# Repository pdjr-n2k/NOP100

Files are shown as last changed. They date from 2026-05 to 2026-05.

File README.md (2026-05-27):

# NOP100

The **NOP100** project implements a generic
[NMEA 2000](https://en.wikipedia.org/wiki/NMEA_2000)
module with on-board support for
[MikroBUS](https://www.mikroe.com/mikrobus)
and
[OneWire]()
devices.

Twin MikroBUS sockets allow specialisation of function by the addition of
[Click](https://www.mikroe.com/click)
expansion cards and appropriate software extensions.

[**NOP100** hardware](./hardware/README.md)
is based on the Teensy 4.0 micro-controller supported by a CAN
transceiver, parasitic power supply and a user configuration
interface.

[**NOP100** firmware](./firmware/README.md)
manages NMEA 2000 connectivity, user interaction and module
configuration and is easily extended by the addition of firmware
dedicated to interfacing any installed MikroBus and OneWire devices.

## Project organisation

```
NOP100/
  + firmware/            # NOP100 firmware...
    + modules/           # Folders for module specialisations
      + NOP100-SIM/        # Specialisation defining an NMEA switch input module
        + defines.h
        + definitions.h
        + includes.h
        + loop.h
        + setup.h
      + another module specialisation/
      + .../
    + NOP100.cpp         # NOP100 main application 
    + README.md
    + defines.h          # Symbolic link to a module specialisation
    + definitions.h      #   "       "
    + includes.h         #   "       "
    + loop.h             #   "       "
    + setup.h            #   "       "
  + hardware/            # NOP100 hardware...
    + gerber/            # Gerber files for PCB fabrication
    + kicad/             # Kicad design for the NOP100 motherboard
    + README.md
```

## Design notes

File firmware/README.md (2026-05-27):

# NOP100/firmware

```NOP100.cpp``` implements a runnable, extensible, firmware for
[NOP100-based hardware](../hardware/README.md).

The files defines.h, definitions.h, includes.h, loop.h and setup.h
allow specialisation of NOP100 to a particular application by
extending and overriding some core functionality.

If specialisation is absent, the firmware creates an NMEA 2000
device with Class Code 10 (System Tools) and Function Code 130
(Diagnostic).
The created device is essentially passive, but will respond to
PGN 126208 Group Function Handler commands to update its default
instance address.

Supplying functional content in the specialisation files allows the
construction of a useful NMEA 2000 application.
The recommended way of doing this is to create a folder under the
```modules/``` directory for a planned application and to populate this
with specialisation files that become the target of symbolic links in
the NOP100 folder.

By way of illustration, the ```modules/NOP100-SIM``` folders contains
code which specialises the NOP100 firmware so that it acts as an NMEA
2000 switch input module.
The extended firware supports one or two
[MikroE 5981]()
modules as the external switch input interface.

The modules/CLICK5981 folder, for example, 
Most useful applications will exploit interfaces implemented by
MikroBus modules which plug into the NOP100 motherboard and it is
[SIM108 - NMEA 2000 switch input module](https://www.github.com/preeve9534/SIM108/)
project is based on NOP100 and gives a working example of a real-world
application.

## Module configuration

Modules based on NOP100 are intended to support structured
configuration updates via PGN126208 Command Group Function or by use
of the hardware DIL switch which allows byte-level updates to binary
configuration data. This restricts the configuration data cache to a
size of 256 bytes with 254 bytes available to the application.

The Teensy microcontroller has a about 1KB of EEPROM available and if
you want to access more than 256 bytes of this storage then you will
need to override NOP100's simple configuration model with a more
elaborate one of your own.

If you do this, make sure that your application configuration data
leaves address locations 0 and 1 for use by NOP100.

| Address | Saved value |
| ---:    | :---        |
| 0       | CAN source address. Not available for application use. |
| 1       | Module instance number. Not available for application use. |
| 2...    | Available for application use. |

Entry of configuration data into NOP100 requires a value to be set on
the PCB's DIL switch and then confirmed by press and release of the PRG
button.
A short press of PRG signifies the entry of a data value; a long press
of PRG signifies entry of an address and, in this latter case, the
expectation is that address entry will promptly be followed by the
entry of a data value which should be stored at the pre-set address.

If a value is entered without a preceeding address then the entered
value is stored at address 1 and will become the module's new instance
number.

Storage locations with an address greater than or equal to two are
intended for application configuration data and entry of this data
requires the entry of an address followed by entry of the value to be
stored at this address.

When an address is entered, the transmit LED will flash rapidly
indicating that the system is waiting for entry of a data value.
If a data value is not entered within one minute the data entry protocol
will self-cancel (the transmit LED will stop flashing).

In ```NOP100.cpp``` the configuration process is handled by the
```prgButtonHandler(bool _state_, int _value_)``` function which is
called each time the PRG button is operated.
*state* will be true if the PRG button has been released or false if
the PRG button has been pressed.
In either case, *value* will be set to the current value read from the
DIL switch.

You can override NOP100's built-in behaviour by overriding the button
handler in ```module-declarations.inc```.
For example, the following code disables configuration entirely:
```
#define PRG_BUTTON_HANDLER
void prgButtonHandler(bool state, int value) {
   return;
}
```

## HOW TO

1. Create parent folder for your new application.
   ```
   $> mkdir n2k-projects
   $> cd n2k-projects
   ```
2. Clone a copy of the Arduino firmware build project and this
   project into separate sub-folders.
   ```
   $> git clone https://github.com/preeve9534/firmware-factory
   $> git clone https://github.com/preeve9534/NOP100
   ```
3. Make a directory for your new project and populate it.
   ```
   $> mkdir myapp
   $> cd myapp
   $> cp ../NOP100/NOP100.cpp myapp.cpp
   $> cp ../NOP100/*.inc .
   $> cd ..
   ```
   You can now delete the NOP100 project.
   ```
   rm -rf NOP100
   ```
4. Set up the build environment so that it points to your new
   project.
   ```
   $> cd firmware-factory/sketch
   $> rm src
   $> ln -s ../../myapp src
   $> cd ../..
   ```
   At this juncture you should be able to open the firmware-factory 
   project in your preferred build environment (I use Code) and
   compile a firmware for your application which does nothing. Well,
   not very much.
5. Edit the ```.inc``` files downloaded at (3) to tailor and
   extend the module firmware to the requirements of your
   application.  DO NOT MODIFY myapp.cpp.

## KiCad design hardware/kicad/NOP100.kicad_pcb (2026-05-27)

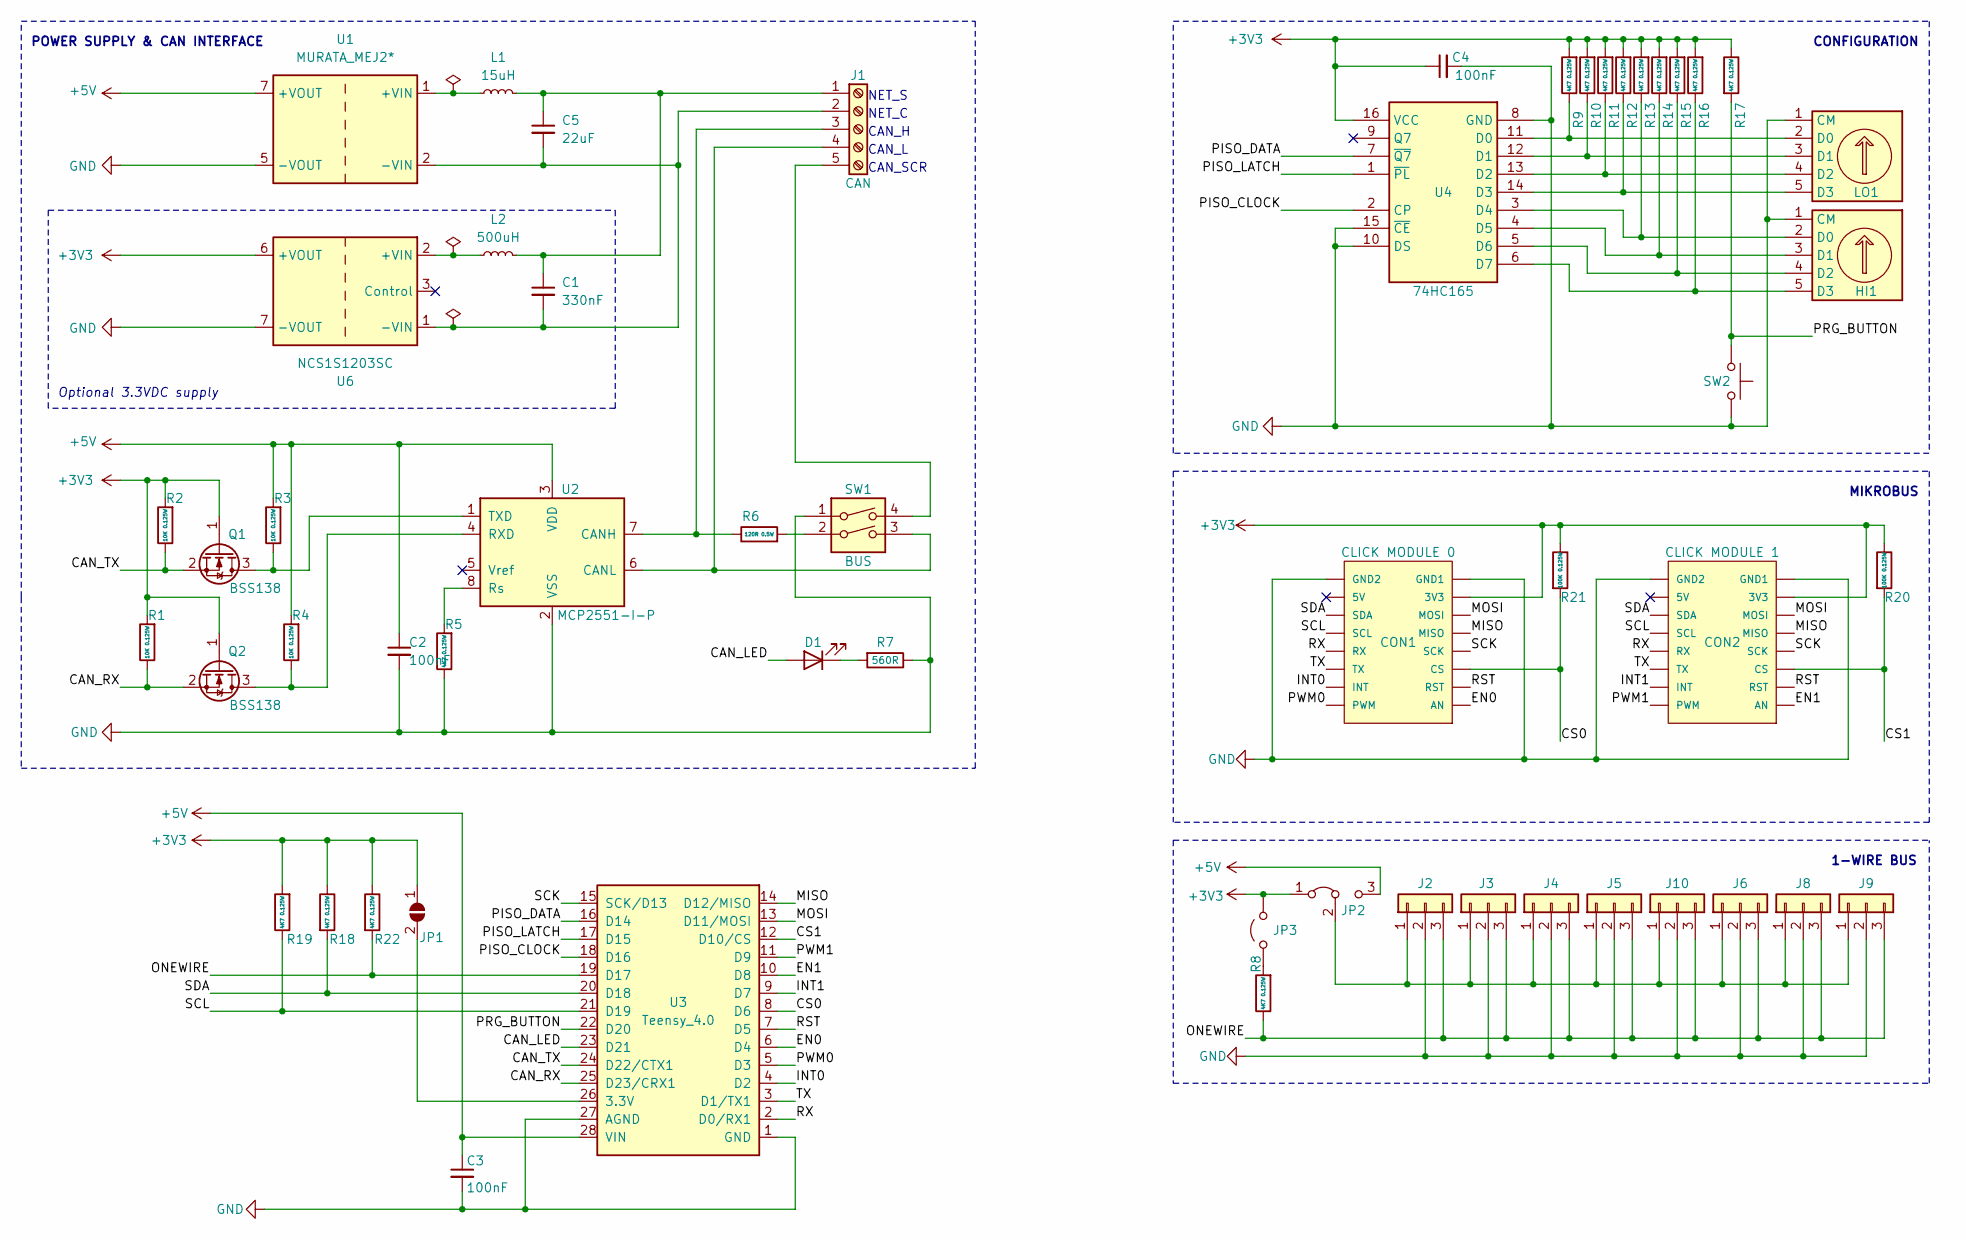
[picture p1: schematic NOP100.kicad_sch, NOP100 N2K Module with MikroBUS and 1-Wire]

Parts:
C1: 330nF; R_1210_3225Metric
C2, C3, C4: 100nF; R_0805_2012Metric
C5: 22uF; R_1210_3225Metric
CON1: CLICK MODULE 0; MIKROBUS_HOST_CONN
CON2: CLICK MODULE 1; MIKROBUS_HOST_CONN
D1: LED; R_0805_2012Metric
HI1: SW_Coded; Nidec_Copal_SH-7010C
J1: CAN; PinHeader_1x05_P2.54mm_Vertical
J2, J3, J4, J5, J6, J8, J9, J10: Conn_01x03; RS_8971054
JP1: SolderJumper_2_Open; SolderJumper-2_P1.3mm_Bridged_Pad1.0x1.5mm
JP2: Jumper_3_Bridged12; PinHeader_1x03_P1.27mm_Vertical
JP3: Jumper_2_Open; PinHeader_1x02_P1.27mm_Vertical
L1: 15uH; L_Bourns_SRN6045TA
L2: 500uH; L_Bourns_SRN6045TA
LO1: SW_Coded; Nidec_Copal_SH-7010C
Q1, Q2: BSS138; SOT-23
R1, R2, R3, R4: 10K 0.125W; R_0805_2012Metric
R5, R8, R9, R10, R11, R12, R13, R14, R15, R16, R17, R18, R19, R22: 4K7 0.125W; R_0805_2012Metric
R6: 120R 0.5W; R_1206_3216Metric
R7: 560R; R_0805_2012Metric
R20, R21: 100K 0.125W; R_0805_2012Metric
SW1: BUS; DIP-4_W7.62mm_LongPads
SW2: SW_Push; SW_SPST_PTS810
U1: MURATA_MEJ2*; Murata-MEJ2*
U2: MCP2551-I-P; SOIC-8_3.9x4.9mm_P1.27mm
U3: Teensy_4.0; DIP-28_W15.24mm_Socket
U4: 74HC165; SOIC-16_3.9x9.9mm_P1.27mm
U6: NCS1S1203SC; Converter_DCDC_Murata_NCS1SxxxxSC_THT

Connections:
+3V3: C4.1, CON1.P7 (3V3), CON2.P7 (3V3), JP1.1 (A), JP2.1 (A), JP3.2 (B), Q1.1 (G), Q2.1 (G), R1.2, R2.2, R9.2, R10.2, R11.2, R12.2, R13.2, R14.2, R15.2, R16.2, R17.1, R18.1, R19.2, R20.1, R21.1, R22.1, U4.16 (VCC), U6.6 (+VOUT)
+5V: C2.1, C3.1, JP2.3 (B), R3.2, R4.2, U1.7 (+VOUT), U2.3 (VDD), U3.28 (VIN)
/CAN_LED: D1.2 (A), U3.23 (D21)
/CAN_RX: Q2.2 (S), R1.1, U3.25 (D23/CRX1)
/CAN_TX: Q1.2 (S), R2.1, U3.24 (D22/CTX1)
/CS0: CON1.P3 (CS), R21.2, U3.8 (D6)
/CS1: CON2.P3 (CS), R20.2, U3.12 (D10/CS)
/EN0: CON1.P1 (AN), U3.6 (D4)
/EN1: CON2.P1 (AN), U3.10 (D8)
/INT0: CON1.P15 (INT), U3.4 (D2)
/INT1: CON2.P15 (INT), U3.9 (D7)
/MISO: CON1.P5 (MISO), CON2.P5 (MISO), U3.14 (D12/MISO)
/MOSI: CON1.P6 (MOSI), CON2.P6 (MOSI), U3.13 (D11/MOSI)
/ONEWIRE: J2.3, J3.3, J4.3, J5.3, J6.3, J8.3, J9.3, J10.3, R8.1, R22.2, U3.19 (D17)
/PISO_CLOCK: U3.18 (D16), U4.2 (CP)
/PISO_DATA: U3.16 (D14), U4.7 (~Q7)
/PISO_LATCH: U3.17 (D15), U4.1 (~PL)
/PRG_BUTTON: R17.2, SW2.1, U3.22 (D20)
/PWM0: CON1.P16 (PWM), U3.5 (D3)
/PWM1: CON2.P16 (PWM), U3.11 (D9)
/RST: CON1.P2 (RST), CON2.P2 (RST), U3.7 (D5)
/RX: CON1.P13 (RX), CON2.P13 (RX), U3.2 (D0/RX1)
/SCK: CON1.P4 (SCK), CON2.P4 (SCK), U3.15 (SCK/D13)
/SCL: CON1.P12 (SCL), CON2.P12 (SCL), R19.1, U3.21 (D19)
/SDA: CON1.P11 (SDA), CON2.P11 (SDA), R18.2, U3.20 (D18)
/TX: CON1.P14 (TX), CON2.P14 (TX), U3.3 (D1/TX1)
GND: C2.2, C3.2, C4.2, CON1.P8 (GND1), CON1.P9 (GND2), CON2.P8 (GND1), CON2.P9 (GND2), HI1.1 (CM), J2.2, J3.2, J4.2, J5.2, J6.2, J8.2, J9.2, J10.2, LO1.1 (CM), R5.1, R7.1, SW1.1, SW2.2, U1.5 (-VOUT), U2.2 (VSS), U3.1 (GND), U3.27 (AGND), U4.8 (GND), U4.10 (DS), U4.15 (~CE), U6.7 (-VOUT)
unnamed: D1.1 (K), R7.2
unnamed: HI1.2 (D0), R13.1, U4.3 (D4)
unnamed: HI1.3 (D1), R14.1, U4.4 (D5)
unnamed: HI1.4 (D2), R15.1, U4.5 (D6)
unnamed: HI1.5 (D3), R16.1, U4.6 (D7)
unnamed: C1.1, C5.1, J1.1, L1.2, L2.2
unnamed: C1.2, C5.2, J1.2, U1.2 (-VIN), U6.1 (-VIN)
unnamed: J1.3, R6.1, U2.7 (CANH)
unnamed: J1.4, SW1.3, U2.6 (CANL)
unnamed: J1.5, SW1.4
unnamed: J2.1, J3.1, J4.1, J5.1, J6.1, J8.1, J9.1, J10.1, JP2.2 (C)
unnamed: JP1.2 (B), U3.26 (3.3V)
unnamed: JP3.1 (A), R8.2
unnamed: LO1.2 (D0), R9.1, U4.11 (D0)
unnamed: LO1.3 (D1), R10.1, U4.12 (D1)
unnamed: LO1.4 (D2), R11.1, U4.13 (D2)
unnamed: LO1.5 (D3), R12.1, U4.14 (D3)
unnamed: Q1.3 (D), R3.1, U2.1 (TXD)
unnamed: Q2.3 (D), R4.1, U2.4 (RXD)
unnamed: R6.2, SW1.2
unnamed: L1.1, U1.1 (+VIN)
unnamed: R5.2, U2.8 (Rs)
unnamed: L2.1, U6.2 (+VIN)

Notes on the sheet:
CONFIGURATION
1-WIRE BUS
MIKROBUS
CAN_H
POWER SUPPLY & CAN INTERFACE
CAN_L
CAN_SCR
NET_C
NET_S
Optional 3.3VDC supply

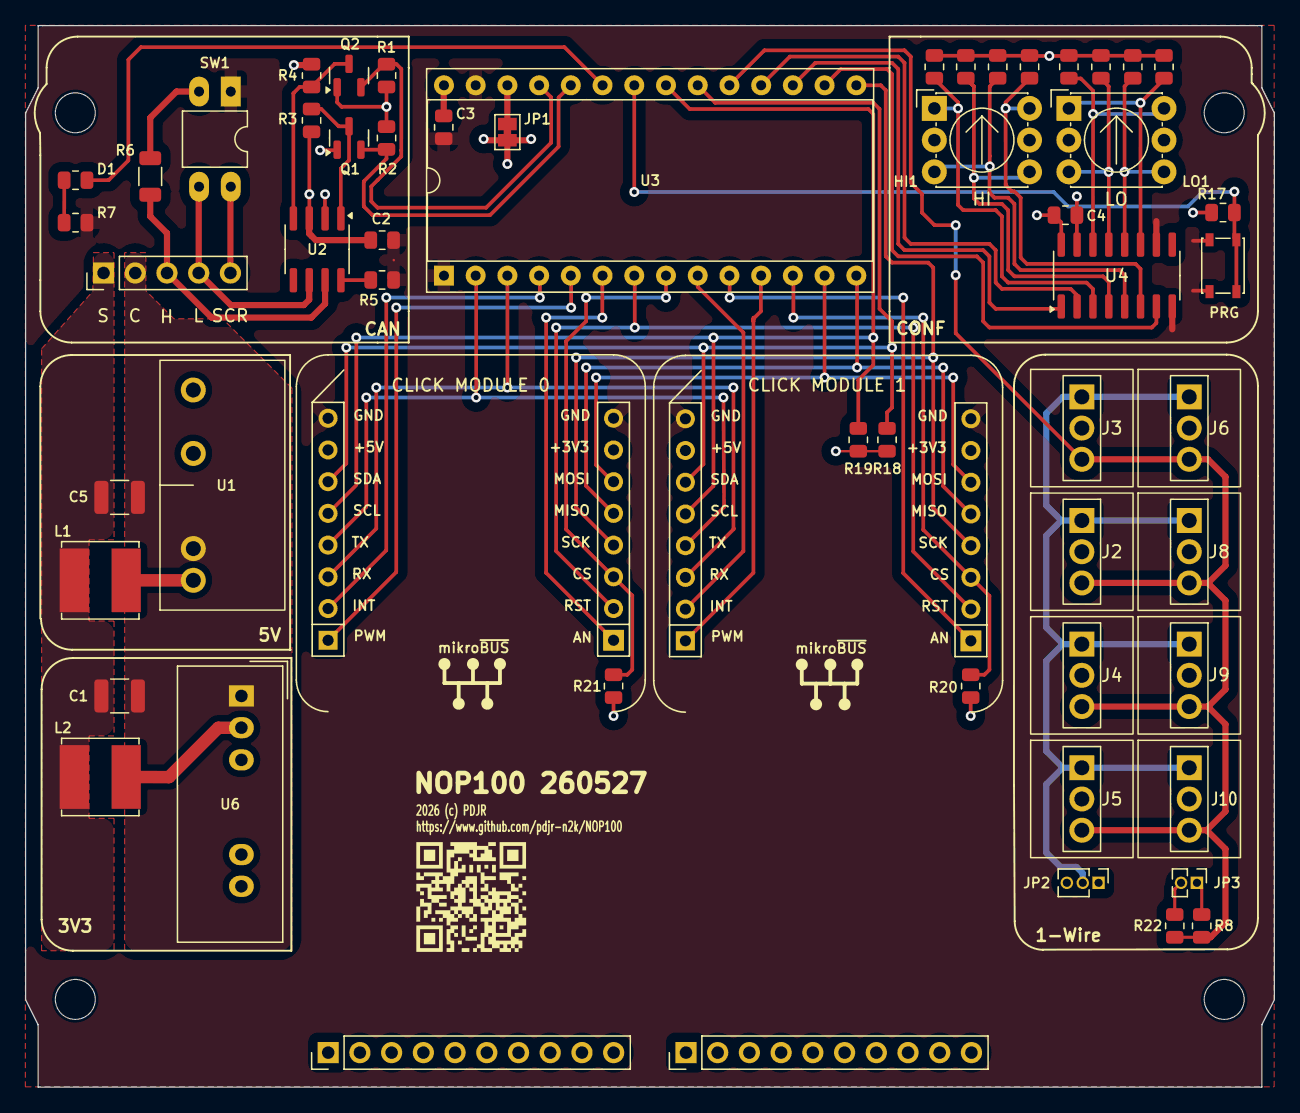
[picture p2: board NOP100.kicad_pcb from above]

Board: 4 copper layers, 100.0 x 85.0 mm, 55 parts (0 on the bottom side), 50 nets.

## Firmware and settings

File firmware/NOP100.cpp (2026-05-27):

/**
 * @file NOP100.cpp
 * @author Paul Reeve (preeve@pdjr.eu)
 * @brief Extensible firmware based on the NMEA2000 library.
 * @version 0.1
 * @date 2023-01-15
 * 
 * @copyright Copyright (c) 2023
 *
 * This firmware is targetted at hardware based on the
 * [NOP100](https://github.com/preeve9534/NOP100)
 * module design.
 * It implements a functional NMEA 2000 device that performs no
 * real-world task, but which can be easily extended or specialised
 * into a variant that can perform most things required of an NMEA 2000
 * module.
 * 
 * Support for NMEA 2000 networking is provided by Timo Lappalainen's
 * [NMEA2000](https://github.com/ttlappalainen/NMEA2000)
 * library.
 * 
 * Support for configuration management and operator interaction
 * is provided by a number of bespoke libraries that relieve derived
 * applications of much of the heavy lifting.
 */

#include <Arduino.h>
#include <EEPROM.h>
#include <NMEA2000.h>
#include <N2kTypes.h>
#include <N2kMessages.h>
#include <NMEA2000_Teensyx.h>
#include <NMEA2000_CAN.h>
#include <Button.h>
#include <IC74HC165.h>
#include <SPI.h>
#include <LedManager.h>
#include <ModuleConfigurator.h>
#include <arraymacros.h>

#include <includes.h>


/**********************************************************************
 * @brief Configure debug output to Teensy serial port.
 */
#define DEBUG_SERIAL
#define DEBUG_SERIAL_PORT_SPEED 9600
#define DEBUG_SERIAL_START_DELAY 4000

/**********************************************************************
 * @brief GPIO pin definitions for Teensy 4.0
 */
#define GPIO_D0 0
#define GPIO_D1 1
#define GPIO_D2 2
#define GPIO_D3 3
#define GPIO_D4 4
#define GPIO_D5 5
#define GPIO_D6 6
#define GPIO_D7 7
#define GPIO_D8 8
#define GPIO_D9 9
#define GPIO_D10 10
#define GPIO_D11 11
#define GPIO_D12 12
#define GPIO_D13 13
#define GPIO_D14 14
#define GPIO_D15 15
#define GPIO_D16 16
#define GPIO_D17 17
#define GPIO_D18 18
#define GPIO_D19 19
#define GPIO_D20 20
#define GPIO_D21 21
#define GPIO_D22 22
#define GPIO_D23 23

#define GPIO_SERIAL_RX GPIO_D0
#define GPIO_SERIAL_TX GPIO_D1
#define GPIO_MIKROBUS_MODULE0_INT GPIO_D2
#define GPIO_MIKROBUS_MODULE0_PWM GPIO_D3
#define GPIO_MIKROBUS_MODULE0_EN GPIO_D4
#define GPIO_MIKROBUS_RST GPIO_D5
#define GPIO_MIKROBUS_MODULE0_CS GPIO_D6
#define GPIO_MIKROBUS_MODULE1_INT GPIO_D7
#define GPIO_MIKROBUS_MODULE1_EN GPIO_D8
#define GPIO_MIKROBUS_MODULE1_PWM GPIO_D9
#define GPIO_MIKROBUS_MODULE1_CS GPIO_D10
#define GPIO_SPI_MOSI GPIO_D11
#define GPIO_SPI_MISO GPIO_D12
#define GPIO_SPI_SCK GPIO_D13
#define GPIO_PISO_DATA GPIO_D14
#define GPIO_PISO_LATCH GPIO_D15
#define GPIO_PISO_CLOCK GPIO_D16
#define GPIO_ONE_WIRE GPIO_D17
#define GPIO_I2C_SDA GPIO_D18
#define GPIO_I2C_SCL GPIO_D19
#define GPIO_BUTTON_PRG GPIO_D20
#define GPIO_LED_CAN GPIO_D21
#define GPIO_CAN_TX GPIO_D22
#define GPIO_CAN_RX GPIO_D23

/**********************************************************************
 * @brief NMEA2000 device information.
 * 
 * Most specialisations of NOP100 will want to override DEVICE_CLASS,
 * DEVICE_FUNCTION and perhaps DEVICE_UNIQUE_NUMBER.
 * 
 * DEVICE_CLASS and DEVICE_FUNCTION are explained in the document
 * "NMEA 2000 Appendix B.6 Class & Function Codes".
 * 
 * DEVICE_INDUSTRY_GROUP we can be confident about (4 says maritime).
 * 
 * DEVICE_MANUFACTURER_CODE is only allocated to subscribed NMEA
 * members so we grub around and use 2046 which is currently not
 * allocated.  
 * 
 * DEVICE_UNIQUE_NUMBER is a bit of mystery.
 */
#define DEVICE_CLASS 10                 // System Tools
#define DEVICE_FUNCTION 130             // Diagnostic
#define DEVICE_INDUSTRY_GROUP 4         // Maritime
#define DEVICE_MANUFACTURER_CODE 2046   // Currently not allocated.
#define DEVICE_UNIQUE_NUMBER 849        // Bump me?

/**********************************************************************
 * @brief NMEA2000 product information.
 * 
 * Specialisations of NOP100 will want to override most of these.
 * 
 * PRODUCT_CERTIFICATION_LEVEL is granted by NMEA when a product is
 * officially certified. We won't be.
 * 
 * PRODUCT_CODE is our own unique numerical identifier for this device.
 * 
 * PRODUCT_FIRMWARE_VERSION should probably be generated automatically
 * from semewhere.
 * 
 * PRODUCT_LEN specifies the Load Equivalence Network number for the
 * product which encodes the normal power loading placed on the host
 * NMEA bus. One LEN = 50mA and values are rounded up.
 * 
 * PRODUCT_N2K_VERSION is the version of the N2K specification witht
 * which the firmware complies. 
 */
#define PRODUCT_CERTIFICATION_LEVEL 0   // Not certified
#define PRODUCT_CODE 002                // Our own product code
#define PRODUCT_FIRMWARE_VERSION "1.1.0 (Jun 2022)"
#define PRODUCT_LEN 1                   // This device's LEN
#define PRODUCT_N2K_VERSION 2100        // N2K specification version 2.1
#define PRODUCT_SERIAL_CODE "002-849"   // PRODUCT_CODE + DEVICE_UNIQUE_NUMBER
#define PRODUCT_TYPE "NOP100"           // The product name?
#define PRODUCT_VERSION "1.0 (Mar 2022)"

/**********************************************************************
 * @brief NMEA_TRANSMITTED_PGNS is a null terminated array initialiser
 * that lists all the PGNs we transmit.
 */
#ifndef NMEA_TRANSMITTED_PGNS
#define NMEA_TRANSMITTED_PGNS { 0L }
#endif

/**********************************************************************
 * @brief NMEA_RECEIVED_PGNS is a an array initialiser consisting of
 * pairs which associate the PGN of a message we will accept to a
 * callback which will accept a received message. For example,
 * { 127501L, handlerForPgn127501 }. The list must terminate with the
 * special flag value { 0L, 0 }.
 */
#ifndef NMEA_RECEIVED_PGNS
#define NMEA_RECEIVED_PGNS  { { 0L, 0 } }
#endif

/**********************************************************************
 * @brief EEPROM_STORAGE_ADDRESS specifies the EEPROM address where
 * module configuration data should be persisted.
 */
#ifndef EEPROM_STORAGE_ADDRESS
#define EEPROM_STORAGE_ADDRESS 0
#endif

/**********************************************************************
 * @brief CAN_SOURCE_ADDRESS specifies the CAN source address that
 * should be used by default when the module first connects to the host
 * bus.
 */
#ifndef CAN_SOURCE_ADDRESS
#define CAN_SOURCE_ADDRESS 0x22
#endif

#ifndef INSTANCE
#define INSTANCE 0x00
#endif

/**********************************************************************
 * @brief LedManager library stuff.
 *
 * NOP100 supports a single LED normally used to indicate CAN bus
 * activity and otherwise used to provide feedback for the
 * configuration user-interface.
 */
#define CAN_LED_UPDATE_INTERVAL 100UL

#include "defines.h"

/**********************************************************************
 * @brief moduleConfiguration is a union used to captures persistent
 * module configuration data. The configuration is defined as a
 * structure and reflected as byte array suitable for saving to and
 * loading from EEPROM.
 * 
 * Any application built on NOP100 will need to declare, define and
 * initialise its own moduleConfiguration and also define the
 * MODULE_CONFIGURATION symbol so that the following minimal default is
 * not used. All specialised moduleConfiguration unions **MUST**
 * include a canSourceAddress field.
 */
#ifndef MODULE_CONFIGURATION
#define MODULE_CONFIGURATION

union tModuleConfiguration {
  #pragma pack(push, 1)
  struct {
    byte canSourceAddress;
    byte instance;
  } structure;
  #pragma pack(pop)
  unsigned char buffer[sizeof(structure)];
};

tModuleConfiguration moduleConfiguration = { .structure={ CAN_SOURCE_ADDRESS, INSTANCE } };

#endif

/**********************************************************************
 * @brief ModuleConfigurator callbacks. 
 */

bool validateAddress(unsigned char address) {
  return((address >= 0) && (address < sizeof(moduleConfiguration.structure)));
}

bool processValue(unsigned char address, unsigned char value) {
  bool retval = false;
  if ((address >= 0) && (address < sizeof(moduleConfiguration.structure))) {
    moduleConfiguration.buffer[address] = value;
    EEPROM.put(EEPROM_STORAGE_ADDRESS, moduleConfiguration.structure);
    retval = true;
  }
  return(retval);
}
 
ModuleConfigurator moduleConfigurator = ModuleConfigurator(processValue, validateAddress);

/**
 * @brief Declarations of local functions.
 */
void messageHandler(const tN2kMsg&);
void onN2kOpen();
bool configurationValidator(unsigned int index, unsigned char value);

/**
 * @brief Create and initialise an array of transmitted PGNs.
 * 
 * Array initialiser is specified in defined.h. Required by NMEA2000
 * library. 
 */
const unsigned long TransmitMessages[] = NMEA_TRANSMITTED_PGNS;

/**
 * @brief Create and initialise a vector of received PGNs and their
 *        handlers.
 * 
 * Array initialiser is specified in defined.h. Required by NMEA2000
 * library. 
 */
typedef struct { unsigned long PGN; void (*Handler)(const tN2kMsg &N2kMsg); } tNMEA2000Handler;
tNMEA2000Handler NMEA2000Handlers[] = NMEA_RECEIVED_PGNS;

/**
 * @brief Button object for debouncing the module's PRG button.
 */
Button PRGButton(GPIO_BUTTON_PRG);

/**
 * @brief Interface to the IC74HC165 PISO IC that connects the eight 
 *        DIL switch parallel inputs.
 */
IC74HC165 CodeSwitchPISO (GPIO_PISO_CLOCK, GPIO_PISO_DATA, GPIO_PISO_LATCH);

/**
 * @brief tLedManager objects for operating the CAN and PRG LEDs.
 * 
 * Both LEDs are connected directly to a GPIO pin, so the lambda
 * callback just uses a digital write operation to drive the output.
 */
LedManager CanLed([](unsigned int status){ digitalWrite(GPIO_LED_CAN, (status & 0x01)); }, CAN_LED_UPDATE_INTERVAL);

#include "definitions.h"

/**********************************************************************
 * MAIN PROGRAM - setup()
 */
void setup() {
  #ifdef DEBUG_SERIAL
  Serial.begin(DEBUG_SERIAL_PORT_SPEED);
  delay(DEBUG_SERIAL_START_DELAY);
  #endif

  // Set the mode of GPIO pins which are not configured by interface
  // libraries.
  pinMode(GPIO_MIKROBUS_MODULE0_CS, OUTPUT);
  pinMode(GPIO_MIKROBUS_MODULE1_CS, OUTPUT);
  pinMode(GPIO_LED_CAN, OUTPUT);

  SPI.begin();

  PRGButton.begin();

  CodeSwitchPISO.begin();
  
  // Run a startup sequence in the LED display: all LEDs on to confirm
  // function.
  CanLed.setStatus(0xff);
  delay(100);
  CanLed.setStatus(0x00);

  #include "setup.h"

  // Load any existing configuration
  EEPROM.get(EEPROM_STORAGE_ADDRESS, moduleConfiguration.structure);

  // Initialise and start N2K services.
  NMEA2000.SetProductInformation(PRODUCT_SERIAL_CODE, PRODUCT_CODE, PRODUCT_TYPE, PRODUCT_FIRMWARE_VERSION, PRODUCT_VERSION);
  NMEA2000.SetDeviceInformation(DEVICE_UNIQUE_NUMBER, DEVICE_FUNCTION, DEVICE_CLASS, DEVICE_MANUFACTURER_CODE);
  NMEA2000.SetMode(tNMEA2000::N2km_ListenAndNode, moduleConfiguration.structure.canSourceAddress); // Configure for sending and receiving.
  NMEA2000.EnableForward(false); // Disable all msg forwarding to USB (=Serial)
  NMEA2000.ExtendTransmitMessages(TransmitMessages); // Tell library which PGNs we transmit
  NMEA2000.SetMsgHandler(messageHandler);
  NMEA2000.SetOnOpen(onN2kOpen);
  NMEA2000.Open();

  #ifdef DEBUG_SERIAL
  Serial.println();
  Serial.println("Starting:");
  Serial.print("  CAN Source address is "); Serial.println(moduleConfiguration.structure.canSourceAddress);
  Serial.print("  N2K instance number is "); Serial.println(moduleConfiguration.structure.instance);
  #endif
}

/**********************************************************************
 * MAIN PROGRAM - loop()
 * 
 * With the exception of NMEA2000.parseMessages() all of the functions
 * called from loop() implement interval timers which ensure that they
 * will mostly return immediately, only performing their substantive
 * tasks at intervals defined by program constants.
 */ 
void loop() {
  
  // Before we transmit anything, let's do the NMEA housekeeping and
  // process any received messages. This call may result in acquisition
  // of a new CAN source address, so we check if there has been any
  // change and if so save the new address to EEPROM for future re-use.
  NMEA2000.ParseMessages();
  if (NMEA2000.ReadResetAddressChanged()) {
    moduleConfiguration.structure.canSourceAddress = NMEA2000.GetN2kSource();
    EEPROM.put(EEPROM_STORAGE_ADDRESS, moduleConfiguration.structure);
    #ifdef DEBUG_SERIAL
    Serial.print("N2K Source address updated to "); Serial.println(moduleConfiguration.structure.canSourceAddress);
    #endif
  }

  #include "loop.h"

  // If the PRG button has been operated, then call the button handler.
  if (PRGButton.toggled()) {
    switch (moduleConfigurator.handleButtonEvent(PRGButton.read(), (unsigned char) (CodeSwitchPISO.read() & 0xff))) {
      case ModuleConfigurator::ADDRESS_ACCEPTED:
        CanLed.setLedState(0, LedManager::ONCE);
        break;
      case ModuleConfigurator::ADDRESS_REJECTED:
        CanLed.setLedState(0, LedManager::THRICE);
        break;
      case ModuleConfigurator::VALUE_ACCEPTED:
        CanLed.setLedState(0, LedManager::TWICE);
        break;
      case ModuleConfigurator::VALUE_REJECTED:
        CanLed.setLedState(0, LedManager::THRICE);
        break;
      default:
        break;
    }
  }

  // Update LED outputs.
  CanLed.update();
  
}

void messageHandler(const tN2kMsg &N2kMsg) {
  int iHandler;
  for (iHandler=0; NMEA2000Handlers[iHandler].PGN!=0 && !(N2kMsg.PGN==NMEA2000Handlers[iHandler].PGN); iHandler++);
  if (NMEA2000Handlers[iHandler].PGN != 0) {
    NMEA2000Handlers[iHandler].Handler(N2kMsg); 
  }
}

#ifndef ON_N2K_OPEN
#define ON_N2K_OPEN
/**
 * @brief Function called by the NMEA2000 library once the CAN bus is
 * active.
 * 
 * @attention Specialisations will probably need to override this
 * function and therefore must define ON_N2K_OPEN.
 */
void onN2kOpen() {
}

#endif

class tN2kGroupFunctionHandlerForPGN126208 : public tN2kGroupFunctionHandler {

  protected:

    virtual bool HandleRequest(const tN2kMsg &N2kMsg, 
                               uint32_t TransmissionInterval, 
                               uint16_t TransmissionIntervalOffset, 
                               uint8_t  NumberOfParameterPairs,
                               int iDev);

  bool HandleCommand(const tN2kMsg &N2kMsg, uint8_t PrioritySetting, uint8_t NumberOfParameterPairs, int iDev) {
    int i;
    int Index;
    uint8_t field;
    size_t InstallationDescriptionSize;
    char InstallationDescription[Max_N2kConfigurationInfoField_len];
    tN2kGroupFunctionTransmissionOrPriorityErrorCode pec=N2kgfTPec_Acknowledge;
    tN2kMsg N2kRMsg;

    SetStartAcknowledge(N2kRMsg, N2kMsg.Source, 126208UL, N2kgfPGNec_Acknowledge, pec, NumberOfParameterPairs);

    StartParseCommandPairParameters(N2kMsg, Index);
    
    // Read new field values...
    for (i = 0; i < NumberOfParameterPairs; i++) {
      field = N2kMsg.GetByte(Index);
      switch (field) {
        case 1: // Module instance
          InstallationDescriptionSize=Max_N2kConfigurationInfoField_len;
          moduleConfiguration.structure.instance = N2kMsg.GetByte(Index);
          AddAcknowledgeParameter(N2kRMsg, i, N2kgfpec_Acknowledge);
          break;
        default:
          AddAcknowledgeParameter(N2kRMsg,i,N2kgfpec_InvalidRequestOrCommandParameterField);
          break;
      }
    }
    pNMEA2000->SendMsg(N2kRMsg,iDev);
    return true;
  }

  public:

    tN2kGroupFunctionHandlerForPGN126208(tNMEA2000 *_pNMEA2000) : tN2kGroupFunctionHandler(_pNMEA2000, 126208L) {


    };

};
